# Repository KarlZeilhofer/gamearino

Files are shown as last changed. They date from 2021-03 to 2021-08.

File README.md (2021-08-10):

# Gamearino

Elektronisches Spielgerät mit 
* Gameboy Tastenlayout
* OLED-Display mit 128x64 Pixel
* Controller: ESP8266EX (Modul ESP-12F)

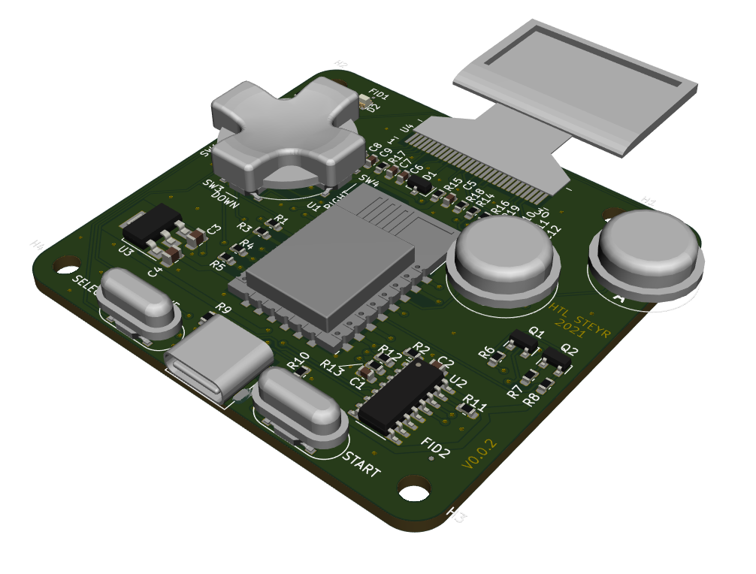
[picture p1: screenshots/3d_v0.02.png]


# OLED
wurde getestet mit dem Arduino Nano mit der Adafruit-Lib. Weil wir keinen Reset-Pin haben, 
muss das Display etwas anders initialisiert werden: 
''display.begin(SSD1306_SWITCHCAPVCC, 0x3c, false);''

Die I2C-Adresse jedenfalls ist 0x3c anstatt 0x3d (Default aus Example Code). 

# Arduino IDE
* ESP8266 installieren: 
  http://arduino.esp8266.com/stable/package_esp8266com_index.json
* Adafruit SSD1306 Lib: 
  Achtung: I2C-Adresse auf 0x3c:
  #define SCREEN_ADDRESS 0x3c

  I2C-Schnittstelle auf GPIO2 und GPIO14 festlegen:
  Wire.begin(14,2); // SDA, SCL
  
# Spiele
Für diese Plattform gibt es zwei Sorten von Spielen: 
1. HTL-Spiele: Spiele von Schülern entwickelt, befindens sich in diesem Repository im Ordner "arduino": https://github.com/KarlZeilhofer/gamearino/tree/main/arduino
2. Arduboy2: Spiele von Profis programmiert. Das originale Repository wurde um die Hardwareportierung erweitert und befindet sich hier: https://github.com/KarlZeilhofer/esp8266_arduboy2

## HTL-Spiele
Für die HTL-Spiele werden folgende Bibliotheken benötigt:
* Adafruit_BusIO
* Adafruit_GFX_Library
* Adafruit_SSD1306
* ESP_EEPROM

## Arduboy Spiele
Für die Arduboy-Spiele braucht es das zweite Repository: https://github.com/KarlZeilhofer/esp8266_arduboy2 und die zugehörigen Bibliotheken, siehe README.md dort. 

# Links
* Arduino ES8266 Core Dokumentation: https://arduino-esp8266.readthedocs.io/en/latest/
* Wikipedia: https://en.wikipedia.org/wiki/ESP8266
* OLED I2C vs. SPI on Youtube: https://www.youtube.com/watch?v=Wz6Fzo3rsLM
* https://www.heise.de/ct/artikel/Arduino-IDE-installieren-und-fit-machen-fuer-ESP8266-und-ESP32-4130814.html
* http://stefanfrings.de/esp8266/
* Adafruit Graphics Library Documentation: https://learn.adafruit.com/adafruit-gfx-graphics-library/overview

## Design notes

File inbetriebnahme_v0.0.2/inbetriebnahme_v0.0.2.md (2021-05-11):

* Bei der Bestückung wurden soll 10k mit ist 12k bestückt, weil keine 10k vorhanden waren. 
* Statt der BAV99 wurde ein NPN-Transistor verwendet für den OLED-Reset. 

* Kurzschluss beim USB-C - Pin in Paste noch suboptimal?
  Pastenauftrag war leicht verschmiert. 

* Die Autoreset-Transistoren sind falsch belegt. 
  Wurde durch drehen um 120° und mit Drahtbrücke gelöst. 
  --> MCU Ist nun programmierbar. 

* OLED Beschaltung optimiert, siehe Screenshot:
  * R17 überbrückt
  * Kathode der Diode auf 3.3V gehängt. 

* Fehler in OLED-Pin-Reihenfolge wurde durch Kupferlackdraht und Skalpell behoben

* SDA und SCL sind im Schaltplan falsch am OLED-Display angeschlossen: 
  IST: 19+20=SCL, 18=SDA
  SOLL: 18 = SCL, 19+20 = SDA

* SCL und SDA wurde in Software ausgetauscht:
  Richtig ist nun: Wire.begin(14, 2) // SDA, SCL

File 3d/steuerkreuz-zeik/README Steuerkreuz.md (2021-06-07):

Steuerkreuz nach dem Vorbild vom Nintendo Gameboy
=================================================

# 3D-Design in FreeCAD
Außenmaße: 21mm
Schenkelbreite: 7mm

Mitte-Mitte-Abstand der SMD-Taster: 14mm

Bauteilhöhe: 5.8mm (von Platinenoberfläche)
Rückhalter: auf Höhe 1.8 bis 2.8mm (1mm dick), 18mm Durchmesser

Kugel: 3mm Radius, liegt auf Platine auf
Kugelausnehmung für Daumen: 25mm Radius
zugehöriger Übergangsradius zur oberen H-Fläche: 5mm

Radius der Innenecken des Kreuzes: 2mm
Radius der Außenecken des Kreuzes: 0.8mm

# 3D-Druck mit Prusa Slicer
0.1mm Schichthöhe
z-Split auf Höhe 2.8mm

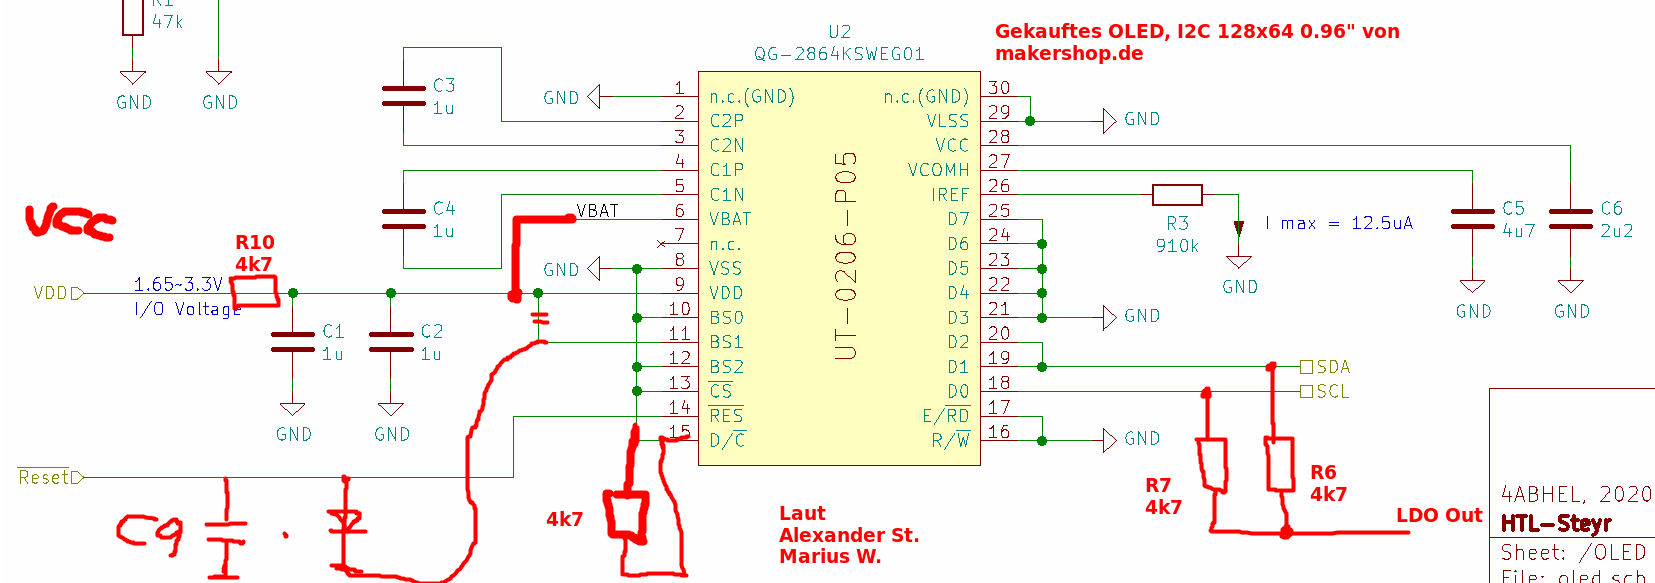
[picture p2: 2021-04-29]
brainstorming/oled-reverse-engineered.png

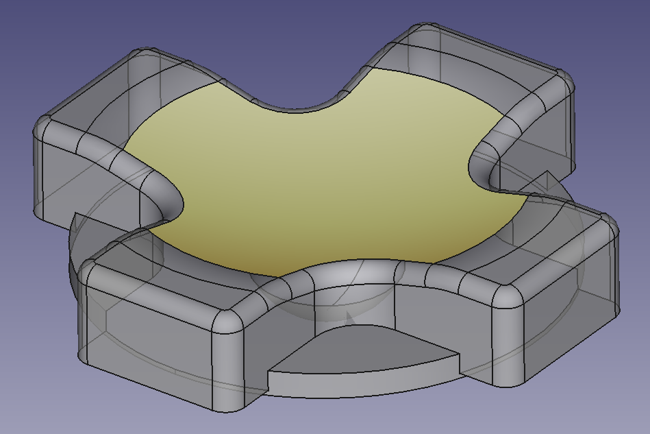
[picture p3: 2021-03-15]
3d/steuerkreuz-zeik/Screenshot from 2021-03-15 12-44-10.png

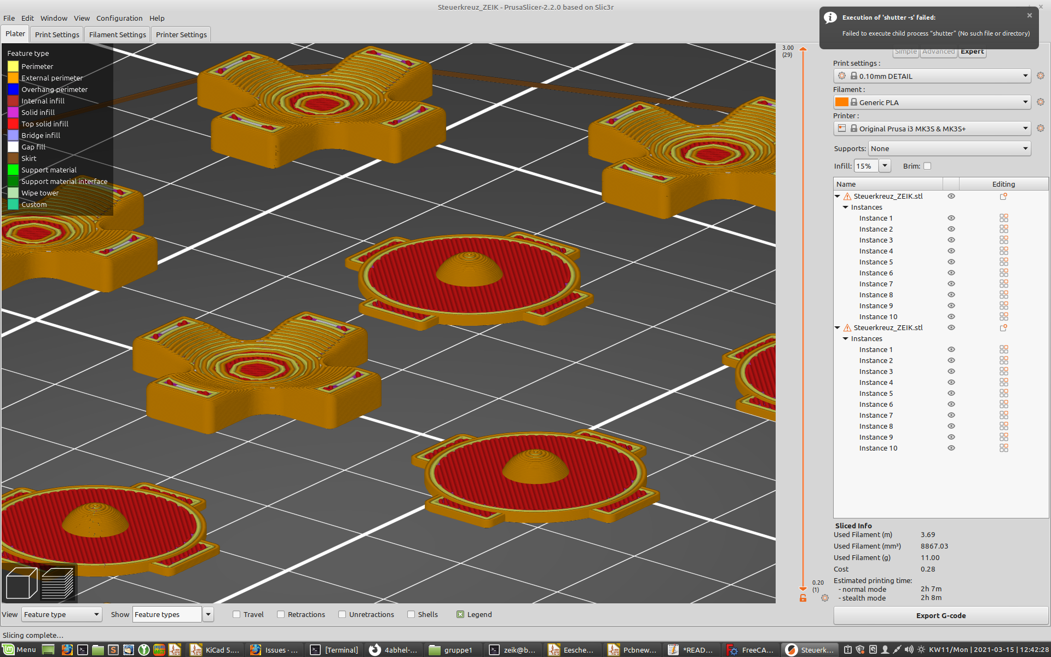
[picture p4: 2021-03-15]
3d/steuerkreuz-zeik/Screenshot from 2021-03-15 12-42-28.png

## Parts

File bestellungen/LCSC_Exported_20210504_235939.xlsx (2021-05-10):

LCSC Part Number | Manufacture Part Number | Manufacturer | Package | Customer # | Description | RoHS | Order Qty. | Min\Mult Order Qty. | Unit Price | Order Price | Product Link
C150387 | CR16-512FV | HDK(Hokuriku Elec Industry) | 0603 |  | 5.1kΩ ±1% 0.1W 0603 Chip Resistor - Surface Mount RoHS | yes | 60 | 20 | 0.0257 | 1.54 | lcsc.com/product-detail/Chip-Resistor-Surface-Mount_HDK-Hokuriku-Elec-Industry-CR16-512FV_C150387.html
C103210 | RTT03103JTP | RALEC | 0603 |  | 10kΩ ±5% 0.1W ±100ppm/℃ 0603 Chip Resistor - Surface Mount RoHS | yes | 600 | 100 | 0.0013 | 0.78 | lcsc.com/product-detail/Chip-Resistor-Surface-Mount_RALEC-RTT03103JTP_C103210.html
C1592 | CL10A105KO8NNNC | Samsung Electro-Mechanics | 0603 |  | 1uF ±10% 16V X5R 0603 Multilayer Ceramic Capacitors MLCC - SMD/SMT RoHS | yes | 350 | 50 | 0.0059 | 2.07 | lcsc.com/product-detail/Multilayer-Ceramic-Capacitors-MLCC-SMD-SMT_Samsung-Electro-Mechanics-CL10A105KO8NNNC_C1592.html
C318884 | TS-1187A-B-A-B | XKB Connectivity | SMD |  | SPST 50mA @ 12VDC Vertical Round Button 160gf SMD Tactile Switches RoHS | yes | 250 | 50 | 0.0155 | 3.88 | lcsc.com/product-detail/Tactile-Switches_XKB-Connectivity-TS-1187A-B-A-B_C318884.html
C103204 | RTT03101JTP | RALEC | 0603 |  | 100Ω ±5% 0.1W ±100ppm/℃ 0603 Chip Resistor - Surface Mount RoHS | yes | 300 | 100 | 0.0031 | 0.93 | lcsc.com/product-detail/Chip-Resistor-Surface-Mount_RALEC-RTT03101JTP_C103204.html
C8667 | PMBT3904,215 | Nexperia | SOT-23(SOT-23-3) |  | NPN 200mA 40V 250mW SOT-23(SOT-23-3) Transistors (NPN/PNP) RoHS | yes | 150 | 50 | 0.013 | 1.95 | lcsc.com/product-detail/Transistors-NPN-PNP_Nexperia-PMBT3904-215_C8667.html
C1713 | CL21A106KOQNNNE | Samsung Electro-Mechanics | 0805 |  | 10uF ±10% 16V X5R 0805 Multilayer Ceramic Capacitors MLCC - SMD/SMT RoHS | yes | 150 | 50 | 0.0147 | 2.21 | lcsc.com/product-detail/Multilayer-Ceramic-Capacitors-MLCC-SMD-SMT_Samsung-Electro-Mechanics-CL21A106KOQNNNE_C1713.html
C181111 | BAV99 | Guangdong Hottech | SOT-23 |  | 70V 200mA 1.25V @ 150mA 6ns SOT-23 Switching Diode RoHS | yes | 100 | 50 | 0.0116 | 1.16 | lcsc.com/product-detail/Switching-Diode_Guangdong-Hottech-BAV99_C181111.html
C125104 | LTST-C195KGJRKT | Lite-On | 0603_x2 |  | Red,Green 631nmRed,571nmGreen 0603_x2 Light Emitting Diodes (LED) RoHS | yes | 80 | 10 | 0.0402 | 3.22 | lcsc.com/product-detail/Light-Emitting-Diodes-LED_Lite-On-LTST-C195KGJRKT_C125104.html
C347222 | AMS1117-3.3 | UMW(Youtai Semiconductor Co., Ltd.) | SOT-223 |  | Fixed 10V 3.3V 1.3V @ 1A SOT-223 Dropout Regulators(LDO) RoHS | yes | 40 | 10 | 0.0559 | 2.24 | lcsc.com/product-detail/Dropout-Regulators-LDO_UMW-Youtai-Semiconductor-Co-Ltd-AMS1117-3-3_C347222.html
C84681 | CH340C | WCH(Jiangsu Qin Heng) | SOP-16_150mil |  | Transceiver USB 2.0 2Mbps SOP-16_150mil USB ICs RoHS | yes | 36 | 1 | 0.3787 | 13.63 | lcsc.com/product-detail/USB-ICs_WCH-Jiangsu-Qin-Heng-CH340C_C84681.html
C82891 | ESP-12F(ESP8266MOD) | Ai-Thinker | WIFI Module |  | WIFI Module WiFi Modules RoHS | yes | 36 | 1 | 1.4941 | 53.79 | lcsc.com/product-detail/WiFi-Modules_Ai-Thinker-ESP-12F-ESP8266MOD_C82891.html
C85007 | QG-2864KSWEG01 | Shenzhen Allvision Tech | 0.96" |  | 0.96" OLED Displays Modules RoHS | yes | 36 | 1 | 2.8953 | 104.23 | lcsc.com/product-detail/OLED-Displays-Modules_Shenzhen-Allvision-Tech-QG-2864KSWEG01_C85007.html
C167321 | 918-418K2023S40001 | Jing Extension of the Electronic Co. | SMD |  | USB - Type C Female 16 SMD USB Connectors RoHS | yes | 36 | 1 | 0.2443 | 8.79 | lcsc.com/product-detail/USB-Connectors_Jing-Extension-of-the-Electronic-Co-918-418K2023S40001_C167321.html

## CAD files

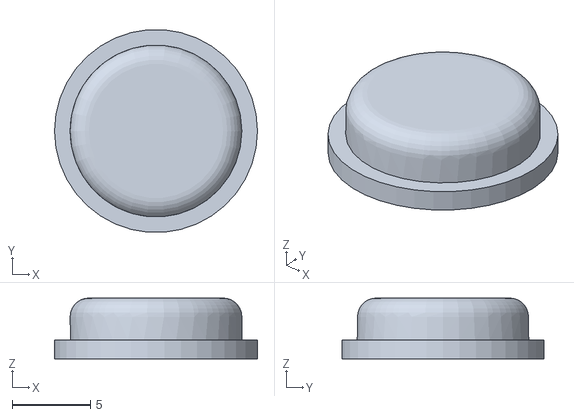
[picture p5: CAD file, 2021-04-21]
3d/ab-buttons/ab-button_v2.stl
13.0 x 13.0 x 3.90

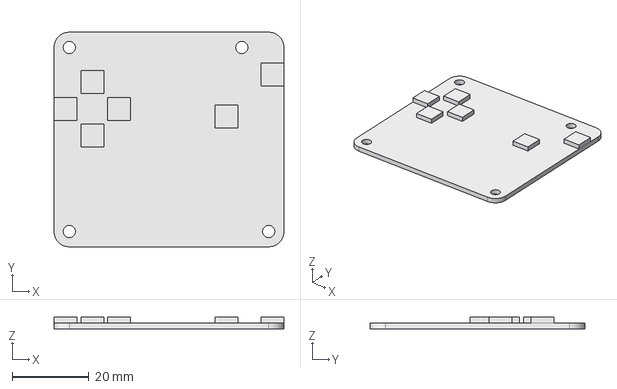
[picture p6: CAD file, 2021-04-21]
3d/dummy-pcb/dummy-pcb.FCStd
60.0 x 56.0 x 3.10 mm

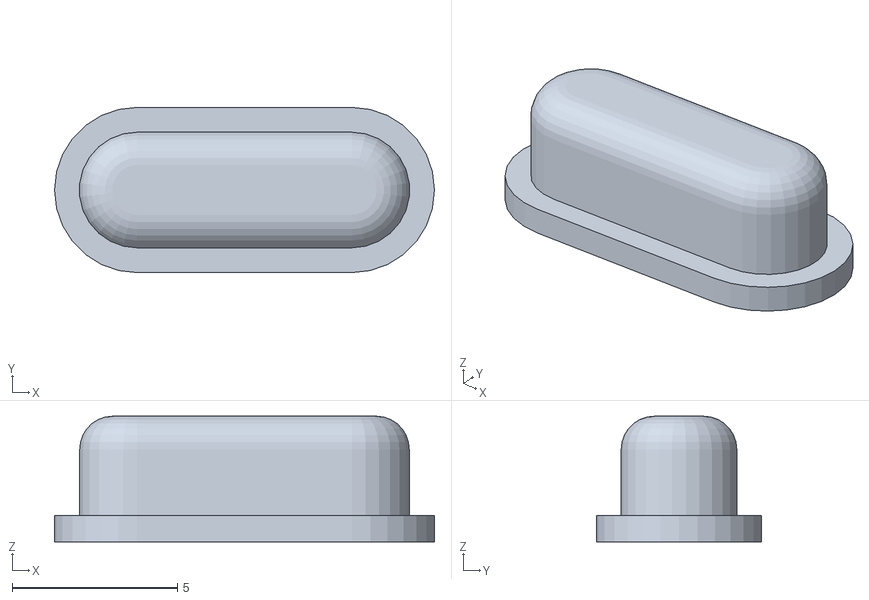
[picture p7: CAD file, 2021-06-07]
3d/gehäuse/gamearino-button_ss_v3.stl
11.5 x 5.00 x 3.80

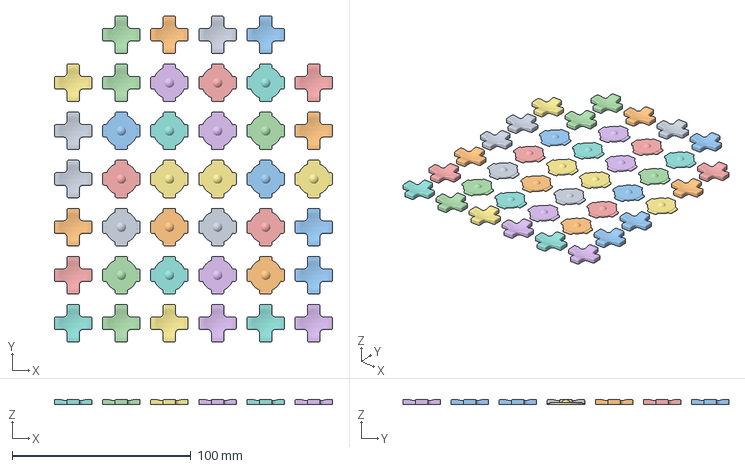
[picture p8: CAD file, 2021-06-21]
3d/prusa/gamearino-steuerkreuz_v2.3mf
155.6 x 182.4 x 3.00 mm
gamearino-steuerkreuz_v2.stl x 2

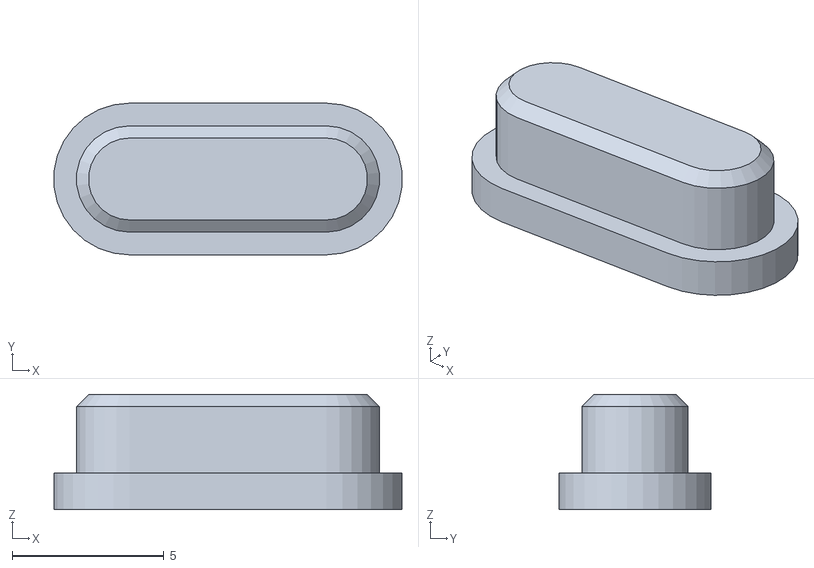
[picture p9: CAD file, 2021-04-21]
3d/start-select-buttons/start-select-button_v1.stl
11.5 x 5.00 x 3.80

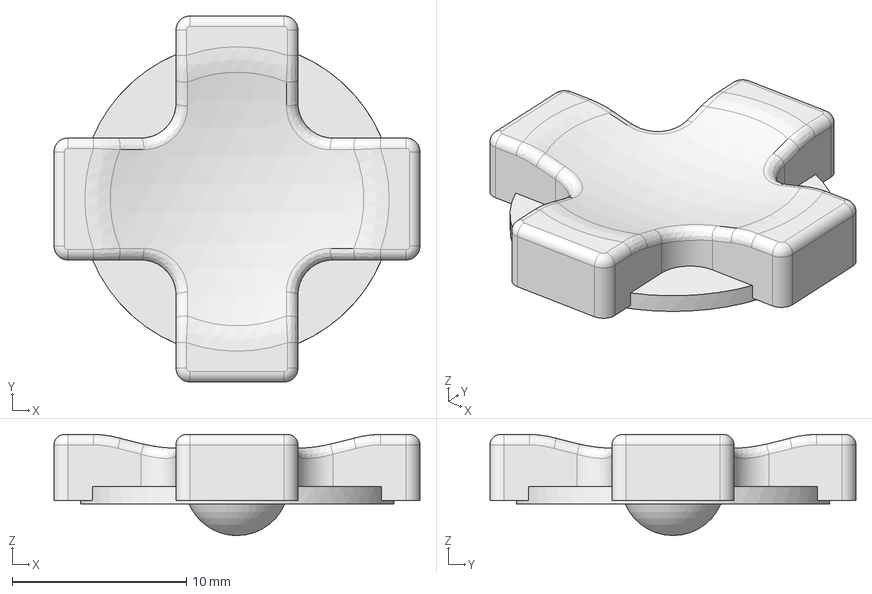
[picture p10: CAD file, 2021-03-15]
3d/steuerkreuz-zeik/steuerkreuz_gameboy_21x7x5.8mm.FCStd
21.0 x 21.0 x 5.80 mm

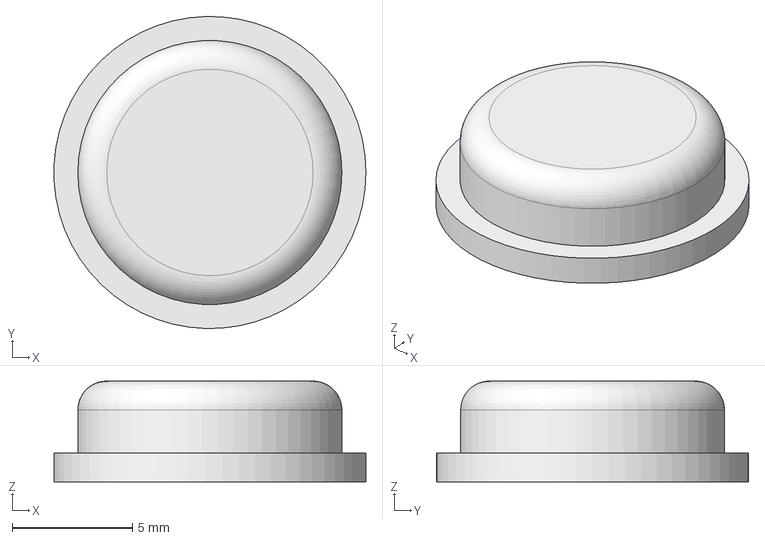
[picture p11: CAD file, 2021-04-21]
3d/ab-buttons/ab-buttons.FCStd
13.0 x 13.0 x 4.20 mm

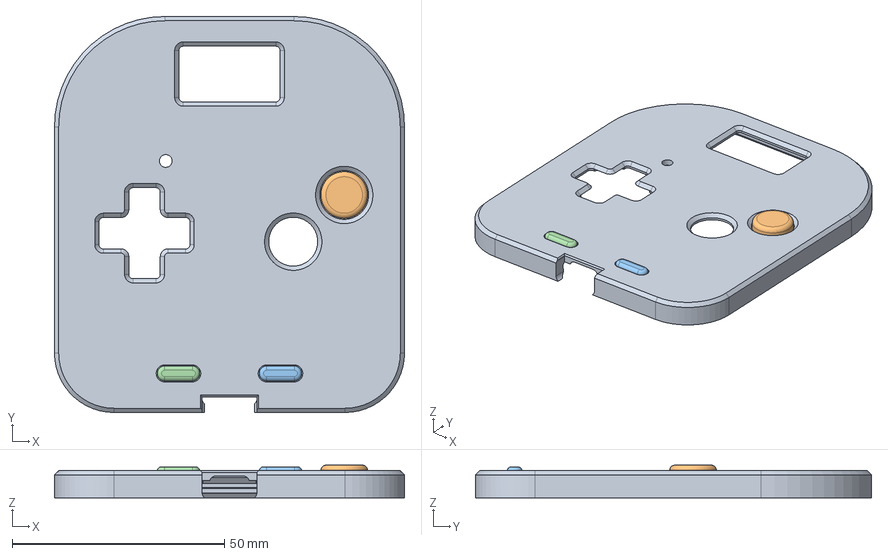
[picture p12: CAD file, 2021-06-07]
3d/gehäuse/gamearino-gehäuseboden.FCStd
82.4 x 93.2 x 7.70 mm
Deckel_v2
Button-A_v3
start-button_v3
select-button_v3

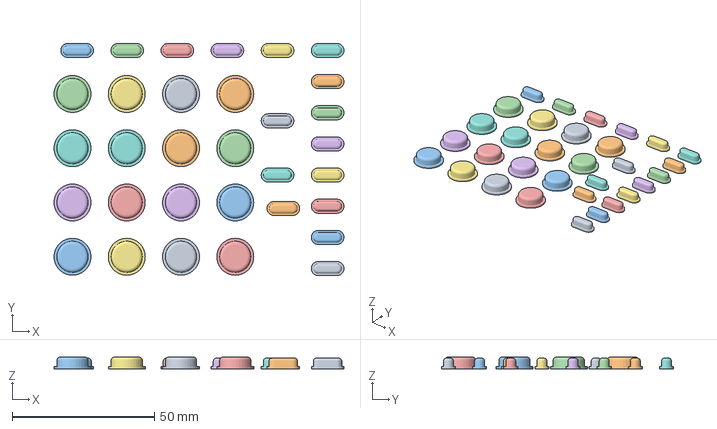
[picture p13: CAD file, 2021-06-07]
3d/prusa/gamearino-buttons_8sets_v3.3mf
101.9 x 81.6 x 4.20 mm
gamearino-button_ab_v3.stl
gamearino-button_ss_v3.stl

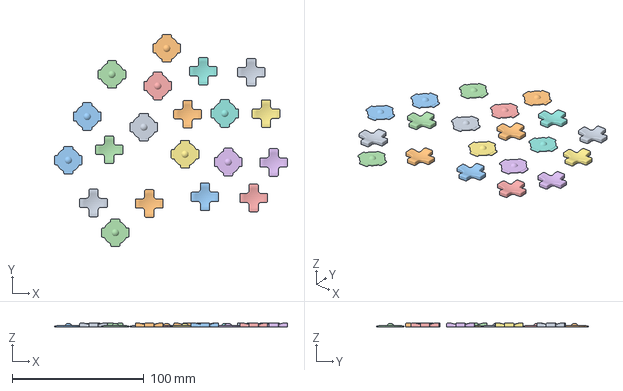
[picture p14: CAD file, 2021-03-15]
3d/steuerkreuz-zeik/Steuerkreuz_ZEIK.3mf
176.8 x 160.8 x 3.00 mm
Steuerkreuz_ZEIK.stl x 2

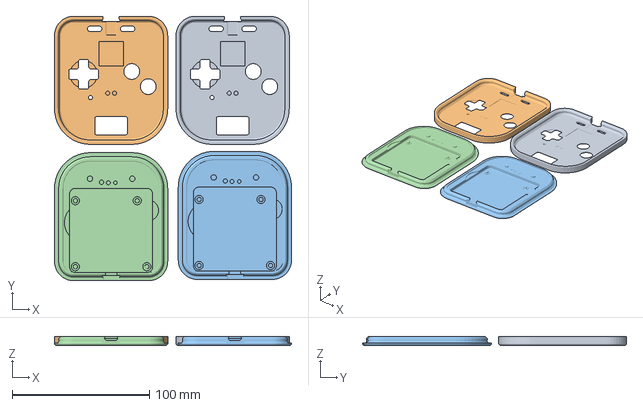
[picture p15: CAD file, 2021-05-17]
3d/prusa/gamearino_deckel-v2_boden-v3.3mf
172.4 x 192.4 x 6.40 mm
gamearino-deckel_v2.stl
gamearino-boden_v3.stl

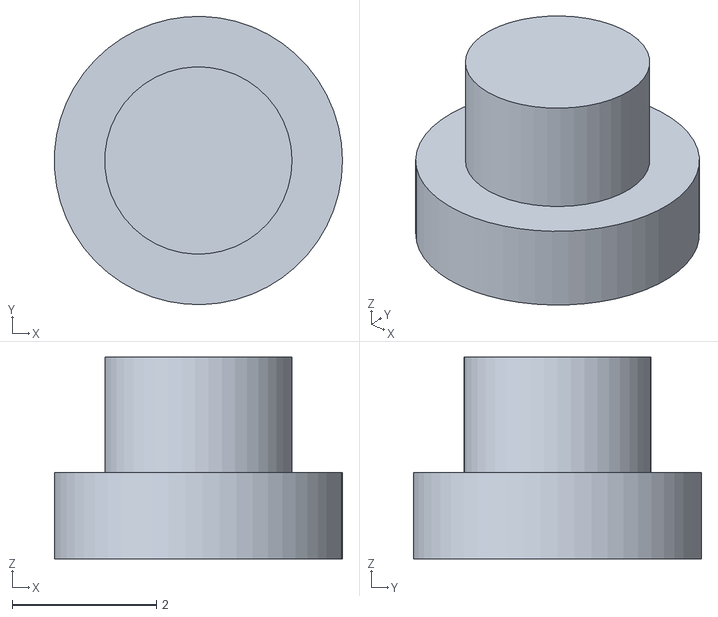
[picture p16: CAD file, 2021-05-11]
3d/gehäuse/gamearino-button_reset_v1.stl
4.00 x 4.00 x 2.80

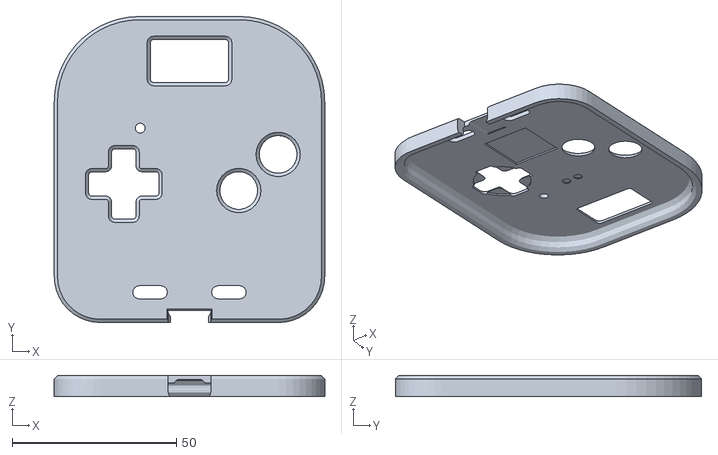
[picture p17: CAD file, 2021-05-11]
3d/gehäuse/gamearino-deckel_v2.stl
82.4 x 93.2 x 6.40

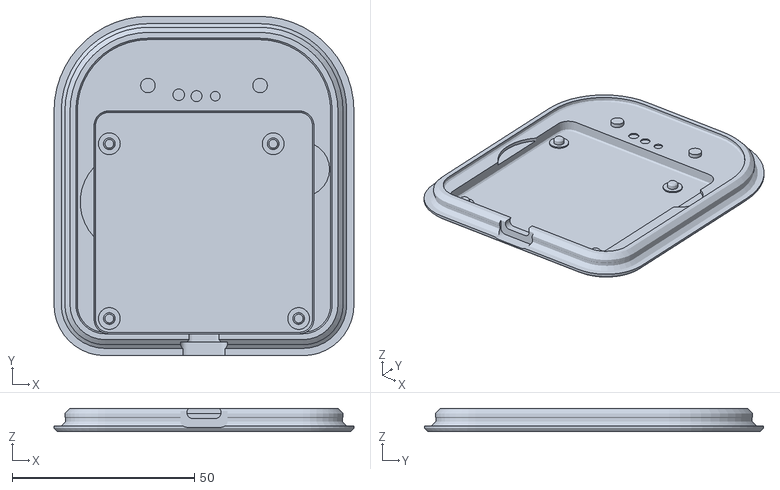
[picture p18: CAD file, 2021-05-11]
3d/gehäuse/gamearino-boden_v3.stl
82.4 x 93.2 x 6.40

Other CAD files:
3d/start-select-buttons/start-slect-button.FCStd
3d/gehäuse/gamearino-button_ab_v3.stl
3d/gehäuse/gamearino-steuerkreuz_v2.stl
3d/gehäuse/gamearino-deckel_v0.1.stl
3d/dummy-pcb/dummy-pcb.stl
3d/gehäuse/gamearino-boden_v1.stl
3d/gehäuse/gamearino-boden_v2.stl
3d/gehäuse/gamearino-button_ab_v2.stl
3d/gehäuse/gamearino-button_ss_v2.stl
3d/gehäuse/gamearino-deckel_v1.stl
3d/steuerkreuz-zeik/Steuerkreuz_ZEIK.stl

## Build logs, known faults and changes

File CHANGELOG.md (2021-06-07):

Changelog Gamearino
===================

# Elektronik
## V20.0.3 Bugfixes für Erste Serienfertigung
* Reset-Taster hinzugefügt
* DNP Footprint für Kondensator am Reset-Pin
* OLED-Beschaltung korrigiert
* OLED Footprint korrigiert
* NPN Pinnummerierung korrigiert
* 0.7mm-Löcher bei der OLED-Flex-PCB
* Pulldown auf Pin 15 durch fix GND ersetzt
* SDA/SCL richtig gestell
* Gerber Export
* HTML-BOM Export
* Durchgehend V20.0.3

## V0.0.2 Prototyp Multi-CB
* Bauteilsortenreduktion beim LCD: 10uF statt 4.7uF, und 2x1uF statt 2.2uF
* Terminierung der unbenutzten Eingänge am CH340
* 5k1 auf CC1 und CC2 bei USB-C-Stecker
* Verwendung des neuen USB-C Footprints mit Pin in Paste
* Pastenreduktion 30um
* Lötstoppfreistellung: 51um
* 150um Leiterbahnabstand
* 150um Mindestleiterbahnbreite
* Passmarken für SMD-Schablone
* 3D-Modelle für Taster und Steuerkreuz aktualisiert
* Taster beschriftet
* Beschriftungen auf PCB-Rückseite
* Power-LED hinzugefügt (Doppel LED, rot aktiv)
* Bestellung 3 Stk. bei Multi-CB inkl. SMD-Schablone mit 120um

## V0.0.1 - CNC-Prototyp
* Grundbeschaltung des ESP8266 ESP-12F:
  * 10k auf GPIO15 gegen GND
  * 10k auf Enable gegen 3V3
* Programmierschaltung mit Transistoren auf Steckbrett getestet
  Arduino-IDE, Standardeinstellung für NodeMCU 1.0
* OLED-Beschaltung auf Steckbrett getestet
* 3D-Design der Taster und des Steuerkreuzes
* Die 8 Taster werden über eine 3x3-Tastermatrix ausgewertet
* Autoreset: unterer Transistor gespiegelt. Beide sind NPN. 
* Pinbelegungsliste als .ods-Datei
* Bemaßungen der Taster
* TODOs aktualisiert: ESP mit OLED erfolgreich getestet
* OLED Demoprogramm
* Tastenanordnung Start/Select und A/B wie beim Original Gameboy (TM)
* USB-Footprint optimiert, inkl. Pin in Paste
* Layout für CNC-Fertigung (ca. 60 Vias!)

# 3D-Druck
* Steuerkreuz: Unterkante von 1.8mm auf Niveau +1.6mm abgesenkt, Haltering bleibt oben +2.8mm
* Gehäuseboden gestaltet
* Dummy-PCB
* Gehäusedeckel probegedruckt
* Deckel-Boden-Paarung: mit 0.2mm-Nut, und identischen Konturen passt es perfekt zusammen
* 3D-Druckteile auf 0.2mm Schichthöhe optimiert (außer Steuerkreuz)
* Deckel V2: 
  * Displayausschnitt nach oben geschoben und rundherum um 1mm vergrößert
  * Senkung für Steuerkreuz von 0,4 auf 0,6mm vergrößert (Steuerkreuz spießt sich bisher)
  * Versionskerben
  * ESP-Senkung mit 0.6 mm (der ist minimal dicker als 2.8 mm)
* Boden V3: 
  * Montage-Sockeln: Stutzen von Durchmesser 3.0 auf 3.2 mm vergrößert
  * Versionskerben
  * Senkungen für Steuerkreuz und A-Taster im Gehäuserand
* Buttons (A/B und Start/Select) V3:
  * Rückhaltesteg von 1.2mm auf 0.8mm reduziert, Knöpfe klemmten im Gehäuse, sodass der Taster immer gedrückt war
  * Gesamtdickt gleich belassen
## TODOs
* Gehäuse dokumentieren

# Spiele
## Snake
* Grundsätzliche Funktion vorhanden
* Button-Klasse in Hardware-Test implementiert
* Highscore
* Asynchrones Warten und Tasten einlesen

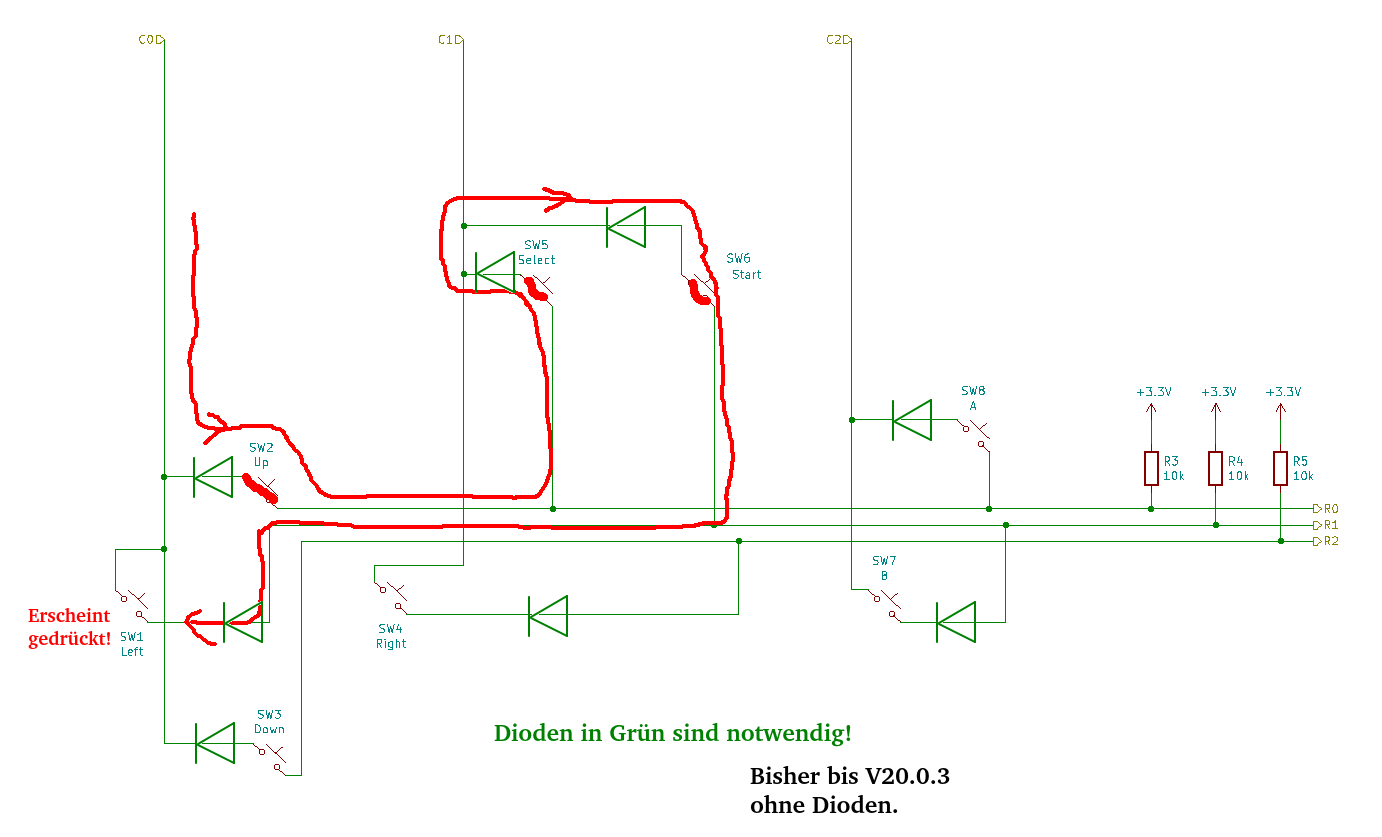
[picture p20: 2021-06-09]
bugreports/issue20.png

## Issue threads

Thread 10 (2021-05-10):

Reset über RTS nach Flashen funktioniert nicht richtig

KarlZeilhofer, 2021-05-10:
evt. sollte noch 1uF zum Resetpin geschaltet werden, siehe ESP-Wroom-Audio. In v0.0.2 ist gar kein Kondensator am Reset

KarlZeilhofer, 2021-05-11:
Das Problem konnte nun nicht mehr festgestellt werden. Ein Footprint wird jedoch vorgesehen in V20.0.3

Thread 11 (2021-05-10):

Reset-Taster wäre nicht schlecht

KarlZeilhofer, 2021-05-10:
Die ersten UART-Ausgaben sind ohne dem Reset-Taster nicht zu sehen.

Bedienung über zusätzlichen Drückknopf oder über Loch im Deckel für Büroklammer.

KarlZeilhofer, 2021-05-11:
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

Closed 2021-05-11.

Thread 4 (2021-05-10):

Deckel/Steuerkreuz: Steuerkreuz ist schwergängig

KarlZeilhofer, 2021-05-10:
Es lässt sich nur die linke Taste leicht drücken. Offenbar fehlt der Freiraum nach oben an der gegenüberliegenden Seite.

KarlZeilhofer, 2021-05-11:
Senkung wurde von 0,4 mm auf 0,6 mm im Deckel vergrößert

Closed 2021-05-11.

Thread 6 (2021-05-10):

PCB: 0.7mm-Löcher bei der Flex-Leiterplatte zu klein

KarlZeilhofer, 2021-05-10:
v0.0.2: sollten 0.7mm haben, sind aber nur 0,4mm

KarlZeilhofer, 2021-05-11:
wurde in v20.0.3 korrigiert

Closed 2021-05-11.

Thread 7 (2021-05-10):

OLED-Beschaltung

KarlZeilhofer, 2021-05-10:
Verbesserungsvorschläge, ausgehend vom Stand v0.0.2:
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

Viele Hinweise auf eevBlog Forum: https://www.eevblog.com/forum/beginners/cant-get-ssd1306-oled-working-on-custom-pcb/

KarlZeilhofer, 2021-05-11:
# SDA und SCL sind auch vertauscht!
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

KarlZeilhofer, 2021-05-11:
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

Gefixt in V20.0.3

Closed 2021-05-11.

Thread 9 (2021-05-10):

Pin-Belegung NPN PMBT3904,215 falsch!

KarlZeilhofer, 2021-05-10:
In v0.0.2 ist diese Belegung zu finden:
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

Laut Datenblatt ist aber folgende Belegung:
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

D.h. statt Device:Q_NPN_BCE muss Device:Q_NPN_BEC verwendet werden!

KarlZeilhofer, 2021-05-11:
![Uploading 2021-05-11_007.png…]()

KarlZeilhofer, 2021-05-11:
# V20.0.3:

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

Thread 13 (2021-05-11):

Reset-Taster Designen

KarlZeilhofer, 2021-05-11:
Deckel Oberseite ist auf 4,4mm
Deckel Unterseite ist auf 2,8mm
Taster ungedrückt auf 1,5mm

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

KarlZeilhofer, 2021-06-09:
Passt perfekt

Closed 2021-06-09.

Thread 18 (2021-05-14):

Snake: Wird sporadisch beendet

KarlZeilhofer, 2021-05-14:
Hier liegt ein Bug vor, dass während des normalen Spiels, das Spiel beendet wird, als ob man gegen eine Wand oder die Schlange gefahren wäre. Ich hab schon bis zu 32 Punkte erreicht, manchmal passiert das aber schon mit 6 Punkten.

KarlZeilhofer, 2021-05-14:
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

Bug wurde gefunden und in commit 28f7e240cf821dac9837e5fc96d309608dc1e1ef behoben

KarlZeilhofer, 2021-05-14:
# Fehlerhaftes Beenden:

## Hier ist offensichtlich, dass die Schlange gar nicht richtig interpretiert wird.
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

## Auch hier wurde das Spiel aus heiterem Himmel beendet:
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

## Korrekte Darstellung und Eigenkollision nach dem Bugfix:
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

Closed 2021-05-14.

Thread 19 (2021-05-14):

Arduboy-Spiele portieren

KarlZeilhofer, 2021-05-14:
Es gibt ein super Projekt dazu:
https://github.com/cheungbx/esp8266_arduboy2

Ich hab es bereits geklont, und die Tasten-Eingabe auf Gamearino umgeschrieben:
https://github.com/KarlZeilhofer/esp8266_arduboy2

Closed 2021-06-09.

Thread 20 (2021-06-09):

Button Matrix Diodes missing

MerlinBlatterer, 2021-06-09:
Diodes in the button matrix are missing.
They are needed in order to prevent ghosting.
One diode for each button

MerlinBlatterer, 2021-06-09:
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

KarlZeilhofer, 2021-06-09:
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

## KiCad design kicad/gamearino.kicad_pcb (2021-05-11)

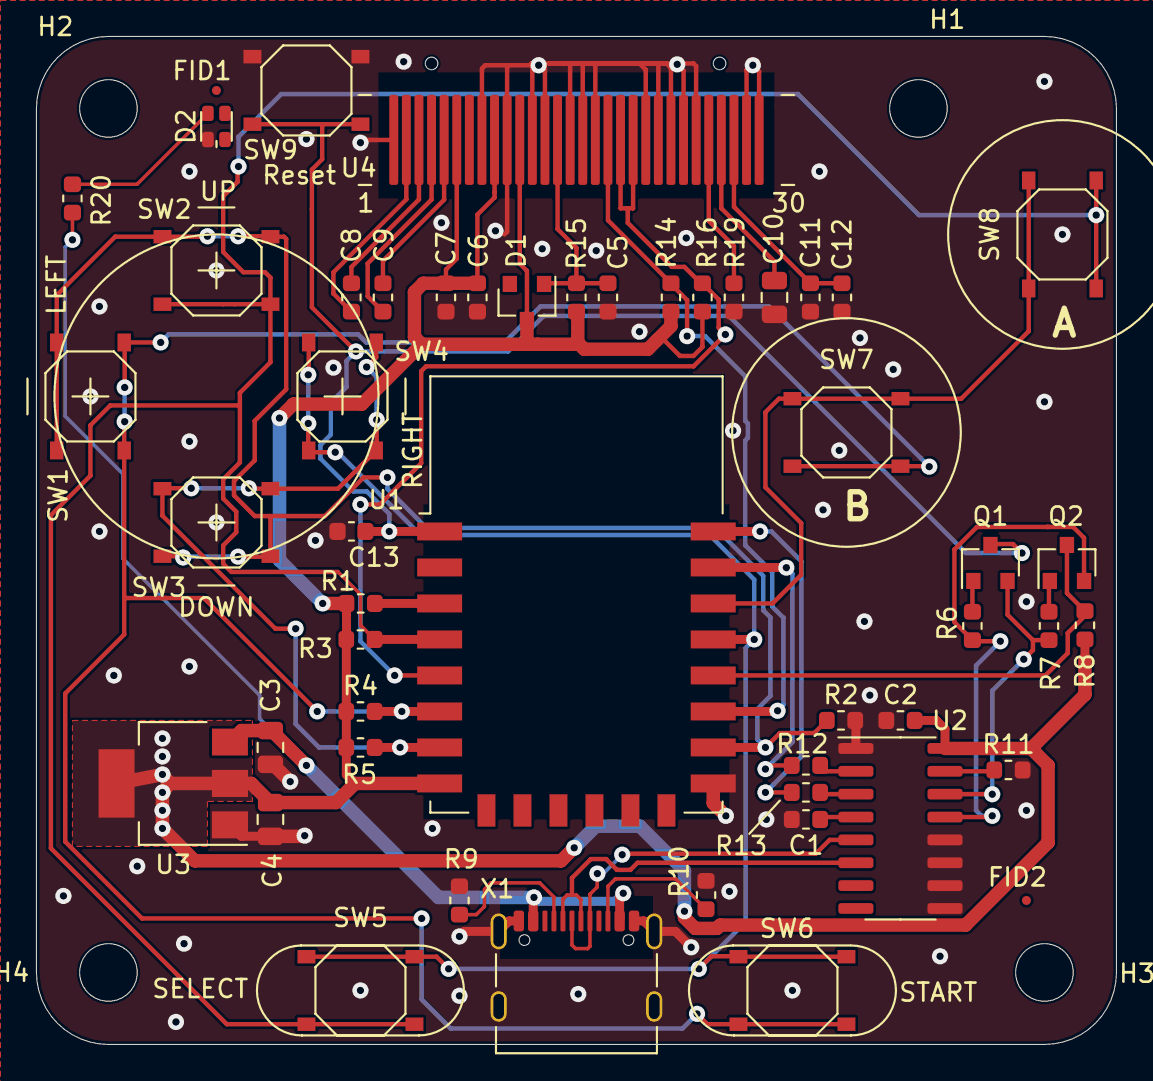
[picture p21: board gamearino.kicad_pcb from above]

Board: 2 copper layers, 60.0 x 56.0 mm, 60 parts (0 on the bottom side), 37 nets.

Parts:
C1, C2: 100n; C_0603_1608Metric
C3, C4, C10: 10u/16V/X5R; C_0805_2012Metric
C5, C6, C7, C8, C9, C11, C12: 1u; C_0603_1608Metric
C13: DNP; C_0603_1608Metric
D1: BAV99; SOT-23
D2: LED_Dual_green-red; LED_LiteOn_LTST-C195KGJRKT
FID1, FID2: Fiducial; paste-fiducial
H1, H2, H3, H4: MountingHole; MountingHole_3.2mm_M3
Item1: 3D Druck: Knopf A; ABKnopf_v2
Item2: 3D Druck: Knopf B; ABKnopf_v2
Item3: 3D Druck: Knopf Start; StartSelect_v2
Item4: 3D Druck: Knopf Select; StartSelect_v2
Item5: 3D Druck: Steuerkreuz; Steuerkreuz_zeik_v2
Q1, Q2: PMBT3904,215; SOT-23
R1, R2, R3, R4, R5, R6, R7, R15: 10k; R_0603_1608Metric
R8, R14, R16, R20: 4k7; R_0603_1608Metric
R9, R10: 5k1; R_0603_1608Metric
R11, R12, R13: 100R; R_0603_1608Metric
R19: 910k; R_0603_1608Metric
SW1: Left; SW_Push_5.1mm_H1.5mm
SW2: Up; SW_Push_5.1mm_H1.5mm
SW3: Down; SW_Push_5.1mm_H1.5mm
SW4: Right; SW_Push_5.1mm_H1.5mm
SW5: Select; SW_Push_5.1mm_H1.5mm
SW6: Start; SW_Push_5.1mm_H1.5mm
SW7: B; SW_Push_5.1mm_H1.5mm
SW8: A; SW_Push_5.1mm_H1.5mm
SW9: Reset; SW_Push_5.1mm_H1.5mm
U1: ESP-12F
U2: CH340C; SOIC-16_3.9x9.9mm_P1.27mm
U3: AMS1117-3.3; SOT-223-3_TabPin2
U4: QG-2864KSWEG01; OLED_128x64_FlatRibbon_30
X1: USB-C/16p; USB_C_Receptacle_LCSC_C167321

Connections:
+3V3: C2.2, C4.1, C6.1, C7.1, D1.3, R1.1, R3.1, R4.1, R5.1, R8.1, R14.2, R15.1, R16.2, U1.8, U2.16, U3.2, U4.6, U4.9, U4.11
/Auto-Reset/DTR: Q2.2, R6.2, U2.13
/Auto-Reset/GPIO0: Q2.3, R8.2, U1.18
/Auto-Reset/RTS: Q1.2, R7.2, U2.14
/Buttons/C0: R2.1, SW1.1, SW2.1, SW3.1, U1.16
/Buttons/C1: SW4.1, SW5.1, SW6.1, U1.19
/Buttons/C2: SW7.1, SW8.1, U1.20
/Buttons/R0: R3.2, SW2.2, SW5.2, SW8.2, U1.4
/Buttons/R1: R4.2, SW1.2, SW6.2, SW7.2, U1.6
/Buttons/R2: R5.2, SW3.2, SW4.2, U1.7
/EN: R1.2, U1.3
/OLED 128x64/SCL: R14.1, U1.17, U4.18
/OLED 128x64/SDA: R16.1, U1.5, U4.19, U4.20
/USB/D+: U2.5, X1.A6, X1.B6
/USB/D-: U2.6, X1.A7, X1.B7
/USB/RxD: R13.1, U1.22
/USB/TxD: R12.2, U1.21
/~RESET: C13.1, Q1.3, SW9.2, U1.1
GND: C1.2, C2.1, C3.2, C4.2, C5.2, C6.2, C7.2, C10.2, C11.2, C12.2, C13.2, D2.4, R2.2, R9.1, R10.2, R11.2, R19.1, SW9.1, U1.15, U2.1, U2.9, U2.10, U2.11, U2.12, U3.1, U4.1, U4.8, U4.10, U4.12, U4.13, U4.15, U4.16, U4.17, U4.21, U4.22, U4.23, U4.24, U4.25, U4.29, U4.30, X1.A1, X1.A12, X1.B1, X1.B12, X1.S1
unnamed: C1.1, U2.4
unnamed: C3.1, R20.1, U3.3, X1.A4, X1.A9, X1.B4, X1.B9
unnamed: C5.1, D1.1, R15.2, U4.14
unnamed: C8.1, U4.2
unnamed: C8.2, U4.3
unnamed: C9.1, U4.4
unnamed: C9.2, U4.5
unnamed: C10.1, U4.27
unnamed: C11.1, C12.1, U4.28
unnamed: D2.2, R20.2
unnamed: Q1.1, R6.1
unnamed: Q2.1, R7.1
unnamed: R9.2, X1.A5
unnamed: R10.1, X1.B5
unnamed: R11.1, U2.15
unnamed: R12.1, U2.2
unnamed: R13.2, U2.3
unnamed: R19.2, U4.26

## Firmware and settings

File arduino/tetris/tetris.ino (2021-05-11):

//TETRIS - TODO-List:
//-Tetrominos müssen sich drehen können
//-Links-Rechts steuerung funktioniert noch nicht optimal, außerdem gibt es noch keine Grenze nach Links/Rechts
//-schnelleres Fallen mit DOWN Button
//-Reihe wird gecleared wenn alle Blöcke voll sind
//-Man verliert wenn man ganz oben ankommt
//-Der nächste Tetromino soll rechts angezeigt weden, so wie ein passender Score
//-Level System, nach gewisser Zeit fallen die Bläcke schneller






typedef struct point {
  uint8_t x;
  uint8_t y;
} point;
#define SCREEN_WIDTH 128 // OLED display width, in pixels
#define SCREEN_HEIGHT 64 // OLED display height, in pixels


#define SEGMENT_TIME 500//Zeit bis 1 Segment vorwärts
#define SEGMENT_SIZE 3
#define START_LEN 3
#define FIELD_SIZE_X 12
#define FIELD_SIZE_Y 21
#define ARR_LEN 100

// Button Matrix 
// UP      C0-R0
// DOWN    C0-R2
// LEFT    C0-R1
// RIGHT   C1-R2
// SELECT  C1-R0
// START   C1-R1
// B       C2-R1
// A       C2-R0


// MCU outputs:
#define MatrixC0 15
#define MatrixC1 4
#define MatrixC2 5
// MCU inputs (hardware pullups 10k):
#define MatrixR0 16
#define MatrixR1 12
#define MatrixR2 13

#define PinSTART 2
#define PinUP 3
#define PinDOWN 4
#define PinLEFT 5
#define PinRIGHT 6
#define TimePrell 30

#include <stdlib.h>
#include <time.h>
#include <SPI.h>
#include <Wire.h>
#include <Adafruit_GFX.h>
#include <Adafruit_SSD1306.h>
#include <EEPROM.h>


// Declaration for an SSD1306 display connected to I2C (SDA, SCL pins)
#define OLED_RESET     -1 // Reset pin # (or -1 if sharing Arduino reset pin)
Adafruit_SSD1306 display(SCREEN_WIDTH, SCREEN_HEIGHT, &Wire, OLED_RESET);


point [4] = {0};
point groundBlock[ARR_LEN] = {0};

uint16_t field [21] = {0};

int num;
uint16_t len = START_LEN;
uint8_t score = 0;
uint8_t highscore = 0;
bool gameRunning = false;
bool inLeaderboard = false;
uint8_t selectedOption = 0;
uint16_t oldtime;
uint16_t starttime;
uint16_t lasttoggle = 0;
int mult;
int turnstate;
int count;
int zw;
point eatPos;
bool firstBlock = true;

int chosenBlock;
int nextBlock

bool pinSTARTLow = true;
bool pinUPLow = true;
bool pinDOWNLow = true;
bool pinLEFTLow = true;
bool pinRIGHTLow = true;
bool pinSELECTLow = true;
bool pinA_Button = true;
bool pinB_Button = true;


unsigned long lastSTART = 0;
unsigned long lastUP = 0;
unsigned long lastDOWN = 0;
unsigned long lastLEFT = 0;
unsigned long lastRIGHT = 0;
unsigned long lastSELECT = 0;
unsigned long lastA_Button = 0;
unsigned long lastB_Button = 0;





enum Buttons {UP, DOWN, LEFT, RIGHT, START, EMPTY} button, oldButton;

uint8_t buttons; // Um mehrere Inputs gleichzeitig verarbeiten zu können
#define UP 1
#define DOWN 2
#define LEFT 4
#define Right 8
#define A_Button 16
#define B_Button 32
#define START 64
#define Select 128

#define LOGO_HEIGHT   16
#define LOGO_WIDTH    16


void setup() {

  Serial.begin(9600);
  Wire.begin(14,2); // SDA, SCL


  // SSD1306_SWITCHCAPVCC = generate display voltage from 3.3V internally
  if (!display.begin(SSD1306_SWITCHCAPVCC, 0x3C, false, false)) { // Address 0x3D for 128x64
    Serial.println(F("SSD1306 allocation failed"));
    for (;;); // Don't proceed, loop forever
  }
  Serial.print(F("Size of SSD1306: "));
  Serial.println(sizeof(display));
  display.clearDisplay();



  pinMode(PinSTART, INPUT_PULLUP);
  pinMode(PinUP, INPUT_PULLUP);
  pinMode(PinDOWN, INPUT_PULLUP);
  pinMode(PinLEFT, INPUT_PULLUP);
  pinMode(PinRIGHT, INPUT_PULLUP);


  if (digitalRead(PinSTART) == LOW && digitalRead(PinUP) == LOW) {

    for (uint8_t i = 0; i < 15; i++) {
      EEPROM.write(i, 0);
    }

  }

  // Clear the buffer
  printWelcomeScreen();

}


void startGame() {
  highscore = EEPROM.read(0);

  display.clearDisplay();
  button = RIGHT;
  oldButton = RIGHT;
  drawBorder();
  formBlock();
  printScore();
  printTime();
  gameRunning = true;
  starttime = millis() / 1000;

}
void printWelcomeScreen() {
  display.clearDisplay();
  display.setTextSize(1);
  display.setTextColor(WHITE);
  display.setCursor(35, 5);
  display.println("Welcome to:");
  display.setTextSize(2);
  display.setCursor(37, 20);
  display.println("TETRIS");
  display.setTextSize(1);
  display.setCursor(52, 43);
  display.println("START");
  display.setTextSize(1);
  display.setCursor(34, 55);
  display.println("LEADERBOARD");
  display.display();
}

void toggleText() {

  //
  uint16_t now = millis();

  if (now - lasttoggle > 1000) {

    lasttoggle = now;
    display.setTextColor(WHITE);
  } else if (now - lasttoggle > 500) {
    display.setTextColor(BLACK);
  } else {
    return;
  }

  if (selectedOption == 0) {
    display.setTextSize(1);
    display.setCursor(52, 43);
    display.println("START");
  } else {
    display.setTextSize(1);
    display.setCursor(34, 55);
    display.println("LEADERBOARD");
  }

  display.display();
}

void printLeaderBoard() {
  display.clearDisplay();
  display.setTextColor(WHITE);
  display.setTextSize(1);
  display.setCursor(0, 0);
  display.println("NUM: SCORE:   TIME:");
  for (uint16_t i = 0; i <= 4; i++) {
    display.drawRect(0, (i * 10) + 10, 20, 11, SSD1306_WHITE);
    display.drawRect(19, (i * 10) + 10, 50, 11, SSD1306_WHITE);
    display.drawRect(68, (i * 10) + 10, 60, 11, SSD1306_WHITE);
    display.setTextColor(WHITE);
    display.setTextSize(1);
    display.setCursor(8, (i * 10) + 12);
    display.println(i + 1);
    if (EEPROM.read(i * 3) != 0) {
      display.setCursor(35, (i * 10) + 12);
      display.println(EEPROM.read(i * 3));

      char pC16[2];
      pC16[0] = EEPROM.read(i * 3 + 1);
      pC16[1] = EEPROM.read(i * 3 + 2);
      uint16_t ui16;
      memcpy( &ui16, pC16, 2 );

      display.setCursor(85, (i * 10) + 12);
      display.println(ui16);
    }

  }

  display.display();
}

uint8_t getButtonPress() {
  uint8_t rv = 0;
// Button Matrix 
// UP      C0-R0
// DOWN    C0-R2
// LEFT    C0-R1
// RIGHT   C1-R2
// SELECT  C1-R0
// START   C1-R1
// B       C2-R1
// A       C2-R0
  // Test for UP, LEFT or DOWN
  digitalWrite(MatrixC0, LOW);
  digitalWrite(MatrixC1, HIGH);
  digitalWrite(MatrixC2, HIGH);

  if (millis() - lastUP > TimePrell) {
    int valUP = digitalRead(MatrixR0);
    if (checkButton(valUP, &pinUPLow, &lastUP) == true) {
      Serial.println("UP");
      rv |= UP;
    }
  }
  if (millis() - lastLEFT > TimePrell) {
    int valLEFT = digitalRead(MatrixR1);
    if (checkButton(valLEFT, &pinLEFTLow, &lastLEFT) == true) {
      Serial.println("LEFT");
      rv|= LEFT;
    }
  }
  if (millis() - lastDOWN > TimePrell) {
    int valDOWN = digitalRead(MatrixR2);
    if (checkButton(valDOWN, &pinDOWNLow, &lastDOWN) == true) {
      Serial.println("DOWN");
      rv |= DOWN;
    }
  }

  // Test for SELECT, START or RIGHT
  digitalWrite(MatrixC0, HIGH);
  digitalWrite(MatrixC1, LOW);
  digitalWrite(MatrixC2, HIGH);

  if (millis() - lastSELECT > TimePrell) {
    int valSELECT = digitalRead(MatrixR0);
    if (checkButton(valSELECT, &pinSELECTLow, &lastSELECT) == true) {
      Serial.println("SELECT");
      rv |= SELECT;
    }
  }

  if (millis() - lastSTART > TimePrell) {
    int valSTART = digitalRead(MatrixR1);
    if (checkButton(valSTART, &pinSTARTLow, &lastSTART) == true) {
      Serial.println("START");
      rv |= START;
    }
  }

  if (millis() - lastRIGHT > TimePrell) {
    int valRIGHT = digitalRead(MatrixR2);
    if (checkButton(valRIGHT, &pinRIGHTLow, &lastRIGHT) == true) {
      Serial.println("RIGHT");
      rv |= RIGHT;
    }
  }

  // Test for A, B or Reserved
  digitalWrite(MatrixC0, HIGH);
  digitalWrite(MatrixC1, HIGH);
  digitalWrite(MatrixC2, LOW);

// TODO: Implement A Button
if (millis() - lastA_Button > TimePrell) {
    int valA_Button = digitalRead(MatrixR0);
    if (checkButton(A_Button, &pinA_ButtonLow, &lastA_Button) == true) {
      Serial.println("A");
      rv |= A;
    }
  } 
  // TODO: Implement B Button
  if (millis() - lastB_Button > TimePrell) {
    int valB_Button = digitalRead(MatrixR1);
    if (checkButton(valB_Button , &pinB_ButtonLow, &lastB_Button ) == true) {
      Serial.println("B");
      rv |= B;
    }
  }
  // TODO: Implement Reserved Button


  digitalWrite(MatrixC0, HIGH);
  digitalWrite(MatrixC1, HIGH);
  digitalWrite(MatrixC2, HIGH);

  return rv;
}

bool checkButton(int val, bool* wasLow, unsigned long* lastTime) {
  if (val == LOW && (*wasLow) == true) {
    (*wasLow) = false;
    (*lastTime)=millis();
    return true;
  }
  if (val == HIGH&&(*wasLow)==false) {
    (*lastTime)=millis();
    (*wasLow) = true;
  }
  return false;
}

void loop() {

  button = getButtonPress();

  if (!gameRunning) {
    if (button&START) {
      if (selectedOption == 1) {
        if (!inLeaderboard) {
          inLeaderboard = true;
          button = 0;
          printLeaderBoard();
        } else {
          printWelcomeScreen();
          inLeaderboard = false;
          button = 0;
        }

      } else {
        startGame();
      }
    }


    if (!inLeaderboard && !gameRunning) {

      if (button&UP) {
        selectedOption = 0;
        display.setTextColor(WHITE);

        display.setTextSize(1);
        display.setCursor(34, 55);
        display.println("LEADERBOARD");
      }

      if (button&DOWN) {
        selectedOption = 1;
        display.setTextColor(WHITE);
        display.setTextSize(1);
        display.setCursor(52, 43);
        display.println("START");
      }
      toggleText();
    }


  }


  if (gameRunning) {

    if (button != UP && button != DOWN && button != LEFT && button != RIGHT) {
      button = oldButton;
    }




    control();


    if (borderCross()) {

      gameRunning = false;
      checkHighscore();
      printWelcomeScreen();


      return;

    }



 
if (!collab()) {
 

  for(uint16_t i = 0; i < 4; ++i) {
      display.drawRect(tetro[i].x * SEGMENT_SIZE + 1, tetro[i].y * SEGMENT_SIZE + 1, 2, 2, SSD1306_BLACK);
      tetro[i].y = tetro[i].y + 1;
    } 
    
  for(uint16_t i = 0; i < 4; ++i) {
      display.drawRect(tetro[i].x * SEGMENT_SIZE + 1, tetro[i].y * SEGMENT_SIZE + 1, 2, 2, SSD1306_WHITE);
    }
} else{
      
  for(uint16_t i = 0; i < 4; ++i) {
    tetro[i].y = tetro[i].y - 1;
    field[tetro[i].y] = field[tetro[i].y] | (1 << tetro[i].x);   
  }
  formBlock();
  }
  
  
    button = 0;
    oldButton = 0;

    printTime();
    display.display(); // Daten auf display schreiben.


    delay(SEGMENT_TIME);
  }
}

void checkHighscore() {
  uint16_t time = millis() / 1000 - starttime;


  for (int i = 0; i < 5; i++) {
    char pC16[2];
    pC16[0] = EEPROM.read(i * 3 + 1);
    pC16[1] = EEPROM.read(i * 3 + 2);
    uint16_t readTime;
    memcpy( &readTime, pC16, 2 );
    if (score > EEPROM.read(i * 3) || score == EEPROM.read(i * 3) && readTime > time) {

      for (int j = 4; j > i; j--) {
        EEPROM.write(j * 3, EEPROM.read((j - 1) * 3));
        EEPROM.write(j * 3 + 1, EEPROM.read((j - 1) * 3 + 1));
        EEPROM.write(j * 3 + 2, EEPROM.read((j - 1) * 3 + 2));
      }

      EEPROM.write(i * 3, score);





      EEPROM.write(i * 3 + 1, time & 0xFF);
      EEPROM.write(i * 3 + 2, time >> 8);
      return;
    }
  }
}

void drawBorder() {
  display.drawRect(0, 0, FIELD_SIZE_X * SEGMENT_SIZE + 1, FIELD_SIZE_Y * SEGMENT_SIZE + 1, SSD1306_WHITE);

  display.setTextSize(0.5);

  display.setTextColor(WHITE);
  display.setCursor(98, 0);
  display.println("NEXT");
  display.setCursor(98, 23);
  display.println("SCORE");

//  display.setCursor(98, 45);
 // display.println("Time");
}

void printScore() {
  score = len - 3;
  display.setTextSize(0.5);
  display.setCursor(98, 10);
  if (len > START_LEN) {
    display.setTextColor(BLACK);
    display.println(score - 1);
  }
  display.setCursor(98, 10);
  display.setTextColor(WHITE);
  display.println(len - 3);

  if (score > highscore) {
    highscore = score;
    display.setCursor(98, 33);
    if (highscore != 0) {
      display.setTextColor(BLACK);
      display.println(highscore - 1);
    }
    display.setCursor(98, 33);
    display.setTextColor(WHITE);
    display.println(highscore);
  } else {
    display.setCursor(98, 33);
    display.setTextColor(WHITE);
    display.println(highscore);
  }
}


void printTime() {
  display.setTextSize(0.01);

  display.setTextColor(BLACK);
  display.setCursor(98, 55);


  display.println(oldtime);

  oldtime = millis() / 1000 - starttime;
  display.setTextColor(WHITE);
  display.setCursor(98, 55);


  display.println(oldtime);
}

void formBlock() {
chooseBlocks();
turnstate = 0;
 if(chosenBlock == 0) {
    // I
  tetro[0].x = 3;
  tetro[0].y = 4;
  tetro[1].x = 4;
  tetro[1].y = 4;
  tetro[2].x = 5;
  tetro[2].y = 4;
  tetro[3].x = 6;
  tetro[3].y = 4;

  }else if(chosenBlock == 1) {
    // J
  tetro[0].x = 4;
  tetro[0].y = 3;
  tetro[1].x = 4;
  tetro[1].y = 4;
  tetro[2].x = 5;
  tetro[2].y = 4;
  tetro[3].x = 6;
  tetro[3].y = 4;
  }else if(chosenBlock == 2) {
    // L
  tetro[0].x = 4;
  tetro[0].y = 4;
  tetro[1].x = 4;
  tetro[1].y = 3;
  tetro[2].x = 5;
  tetro[2].y = 3;
  tetro[3].x = 6;
  tetro[3].y = 3;
  }else if(chosenBlock == 3) {
    // O
  tetro[0].x = 4;
  tetro[0].y = 4;
  tetro[1].x = 4;
  tetro[1].y = 3;
  tetro[2].x = 5;
  tetro[2].y = 4;
  tetro[3].x = 5;
  tetro[3].y = 3;
  }else if(chosenBlock == 4) {
    // S
  tetro[0].x = 4;
  tetro[0].y = 4;
  tetro[1].x = 5;
  tetro[1].y = 4;
  tetro[2].x = 5;
  tetro[2].y = 3;
  tetro[3].x = 6;
  tetro[3].y = 3;
  }else if(chosenBlock == 5) {
    // T
  tetro[0].x = 4;
  tetro[0].y = 4;
  tetro[1].x = 5;
  tetro[1].y = 4;
  tetro[2].x = 5;
  tetro[2].y = 3;
  tetro[3].x = 6;
  tetro[3].y = 4;
  }else if(chosenBlock == 6) {
    // Z
  tetro[0].x = 4;
  tetro[0].y = 3;
  tetro[1].x = 5;
  tetro[1].y = 3;
  tetro[2].x = 5;
  tetro[2].y = 4;
  tetro[3].x = 6;
  tetro[3].y = 4; 
  }

      for(uint16_t i = 0; i < 4; ++i) {
      display.drawRect(tetro[i].x * SEGMENT_SIZE + 1, tetro[i].y * SEGMENT_SIZE + 1, 2, 2, SSD1306_WHITE);
    }
 
  display.display(); // daten auf display schreiben.
}



void chooseBlocks() { //generiere einen neuen zufälligen Block

if(firstBlock == true){
chosenBlock = rand() % 7;
firstBlock = false;
}
chosenBlock = nextBlock
nextBlock = rand() % 7;

 display.setCursor(98, 70); // 70 gewählt prüfen !!
 display.println(nextBlock);
 
}



  




void control() {



//if(button==EMPTY){
//  button=oldButton;
//}

  switch (button) {

    case UP:
      if (oldButton == DOWN) {
        button = DOWN;
      }
      break;
    case DOWN:
      if (oldButton == UP) {
        button = UP;
      }
      break;
    case LEFT:
      if (oldButton == RIGHT) {
        button = RIGHT;
      }
      break;
    case RIGHT:
      if (oldButton == LEFT) {
        button = LEFT;
      }
      break;
  }

  oldButton = button;

  switch (button) {
    case UP:

      break;
    case LEFT:
 for(uint16_t i = 0; i < 4; ++i) {
        display.drawRect(tetro[i].x * SEGMENT_SIZE + 1, tetro[i].y * SEGMENT_SIZE + 1, 2, 2, SSD1306_BLACK);
     tetro[i].x = tetro[i].x - 1;
    }
      break;
    case RIGHT:
    for(uint16_t i = 0; i < 4; ++i) {
        display.drawRect(tetro[i].x * SEGMENT_SIZE + 1, tetro[i].y * SEGMENT_SIZE + 1, 2, 2, SSD1306_BLACK);
     tetro[i].x = tetro[i].x + 1;
    }
      break;
    case DOWN:

      break;
  }
  /*
  
  if(button == LEFT) {
 for(uint16_t i = 0; i < 4; ++i) {
        display.drawRect(tetro[i].x * SEGMENT_SIZE + 1, tetro[i].y * SEGMENT_SIZE + 1, 2, 2, SSD1306_BLACK);
     tetro[i].x = tetro[i].x - 1;
    }
} else if(button == RIGHT) {
 for(uint16_t i = 0; i < 4; ++i) {
        display.drawRect(tetro[i].x * SEGMENT_SIZE + 1, tetro[i].y * SEGMENT_SIZE + 1, 2, 2, SSD1306_BLACK);
     tetro[i].x = tetro[i].x + 1;
    }
}

  button = 0;
  oldButton = 0;

 * 
   */
}





bool collab() {
// int a;
// int b;


  for(uint16_t i = 0; i < 4; ++i) {
    if (tetro[i].y > FIELD_SIZE_Y - 2) {
    return true;
   }else if(bitRead(field[tetro[i].y], tetro[i].x) == 1) {
    return true;
   }
  }
  


   
  return false;

}

bool borderCross() {
  if (tetro[0].y > FIELD_SIZE_Y - 1) {
    return true;
  }
  return false;
}

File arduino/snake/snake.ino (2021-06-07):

// License: GPL v2
// Authors: some students from HTBLA Steyr, Austria

/*
 * Features:
 * Lenken mit Steuerkreuz
 * Äpfel fressen
 * Schlange wird pro Apfel um eins länger
 * Geschwindigkeit wird mit jedem Apfel erhöht
 *
 *
 * TODOs:
 * Bugfix, Spiel wird nach 25 Punkten beendet
 * Highscore Liste im ESP-Flash ablegen
 * Punktestand nach Spielende anzeigen
 * Möglichkeit des Pausierens
 */


#include <stdlib.h>
#include <time.h>
#include <SPI.h>
#include <Wire.h>
#include <Adafruit_GFX.h>
#include <Adafruit_SSD1306.h>
#include <ESP_EEPROM.h>
#include <stdint.h>
#include "button.h"


struct Point {
    Point();
    Point(int8_t x, int8_t y);
    bool operator == (Point rhs);
    int8_t x;
    int8_t y;
};
#define SCREEN_WIDTH 128 // OLED display width, in pixels
#define SCREEN_HEIGHT 64 // OLED display height, in pixels


#define SEGMENT_SIZE 3
#define START_LEN 3
#define FIELD_SIZE_X 32
#define FIELD_SIZE_Y 21
#define ARR_LEN 100



// Declaration for an SSD1306 display connected to I2C (SDA, SCL pins)
#define OLED_RESET     -1 // Reset pin # (or -1 if sharing Arduino reset pin)
Adafruit_SSD1306 display(SCREEN_WIDTH, SCREEN_HEIGHT, &Wire, OLED_RESET);


Point snake[ARR_LEN] = {Point(0,0)};

uint16_t headindex;
uint16_t len = START_LEN;
uint8_t score = 0;
uint8_t highscore = 0;
bool gameRunning = false;
bool gamePaused = false;
bool inHighScore = false;
uint8_t selectedOption = 0;
uint16_t oldtime; // seconds
uint16_t starttime; // seconds
Point eatPos;

#define LOGO_HEIGHT   16
#define LOGO_WIDTH    16

enum Direction{UP, DOWN, LEFT, RIGHT};
Direction direction;
#define START_DELAY 500
uint32_t moveDelay=START_DELAY; // start delay in ms


void setup() {
    Serial.begin(115200);
    delay(100);
    Serial.println("Welcome to SNAKE on Gamearino");
    Wire.begin(14,2); // SDA, SCL

    // SSD1306_SWITCHCAPVCC = generate display voltage from 3.3V internally
    if (!display.begin(SSD1306_SWITCHCAPVCC, 0x3C, false, false)) {
        Serial.println(F("SSD1306 allocation failed"));
        for (;;); // Don't proceed, loop forever
    }
    display.clearDisplay();


    // The library needs to know what size you need for your EEPROM variables
    // The minimum size is 16
    // The begin() call is required to initialise the EEPROM library
    EEPROM.begin(16);


    // clear high score TODO with matrix
    if (buttons.start->read() == Button::Pressed &&
            buttons.select->read() == Button::Pressed) {

        for (uint8_t i = 0; i < 15; i++) {
            EEPROM.put(i, 0);
        }
        if(EEPROM.commit()){
            Serial.println("Data written to EEPROM");
        }else{
            Serial.println("Error on EEPROM.commit()");
        }
        buttons.start->clearEvents();
        do{
            buttons.start->read();
        }while(buttons.start->getEvent() != Button::ReleasedEvent);
    }



    // Clear the buffer
    printWelcomeScreen();
}


void startGame() {
    Serial.println("startGame");
    EEPROM.get(0, highscore);

    display.clearDisplay();
    direction = RIGHT;
    drawBorder();
    initializeSnake();
    printScore();
    printTime();
    gameRunning = true;
    starttime = millis() / 1000;
    moveDelay = START_DELAY;
}
void printWelcomeScreen() {
    display.clearDisplay();
    display.setTextSize(1);
    display.setTextColor(WHITE);
    display.setCursor(35, 5);
    display.println("Welcome to:");
    display.setTextSize(2);
    display.setCursor(37, 20);
    display.println("SNAKE");
    display.setTextSize(1);
    display.setCursor(52, 43);
    display.println("START");
    display.setTextSize(1);
    display.setCursor(34, 55);
    display.println("HIGHSCORE");
    display.display();
}

void toggleText() {
    static uint32_t lasttoggle = 0;
    uint32_t now = millis();

    if (now - lasttoggle > 600) {
        lasttoggle = now;
        display.setTextColor(WHITE);
    } else if (now - lasttoggle > 300) {
        display.setTextColor(BLACK);
    } else {
        return;
    }

    if (selectedOption == 0) {
        display.setTextSize(1);
        display.setCursor(52, 43);
        display.println("START");
    } else {
        display.setTextSize(1);
        display.setCursor(34, 55);
        display.println("HIGHSCORE");
    }

    display.display();
}



void loop() {
    buttons.readAll();

    if (!gameRunning) {
        if (buttons.start->getEvent() == Button::PressedEvent) {
            if (selectedOption == 1) {
                if (!inHighScore) {
                    inHighScore = true;
                    paintHighscore();
                } else {
                    printWelcomeScreen();
                    inHighScore = false;
                }
            } else {
                startGame();
            }
        }


        if (!inHighScore && !gameRunning) {

            if (buttons.up->getEvent() == Button::PressedEvent) {
                selectedOption = 0;
                display.setTextColor(WHITE);

                display.setTextSize(1);
                display.setCursor(34, 55);
                display.println("HIGHSCORE");
            }

            if (buttons.down->getEvent() == Button::PressedEvent) {
                selectedOption = 1;
                display.setTextColor(WHITE);
                display.setTextSize(1);
                display.setCursor(52, 43);
                display.println("START");
            }
            toggleText();
        }
    } // end !gameRunning


    if (gameRunning) {
        if(buttons.start->getEvent() == Button::PressedEvent){
            gamePaused = !gamePaused;

            if(!gamePaused){
                repaintField();
            }
        }

        uint32_t now = millis();

        if(!gamePaused){
            control();

            if (bodyCross() || borderCross()) {
                stateDump();

                gameRunning = false;
                updateHighscore();
                printWelcomeScreen();
                return;
            }
        }

        if (snake[headindex] == eatPos) {
            len++;
            newEat();
            moveDelay = 3000/(len+3); // increase speed with length of snake
            printScore();
            display.drawRect(eatPos.x * SEGMENT_SIZE + 1, eatPos.y * SEGMENT_SIZE + 1, 2, 2, SSD1306_WHITE);
        }

        display.drawRect(snake[headindex].x * SEGMENT_SIZE + 1, snake[headindex].y * SEGMENT_SIZE + 1, 2, 2, SSD1306_WHITE);
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

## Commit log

2020-11-09 änderungen aus werkstatt
    [TODO Bauteile für Reset-Programmierschaltung.ods, gamearino.kicad_pcb, gamearino.sch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]
2021-03-15 PCB-Platzierung, 3D-Knöpfe, Schaltung wird noch getestet
    [AB Knopf.step, StartSelect Knopf.step, Steuerkreuz.step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]
2021-03-15 Changelog eingeführt, GND statt GNDD
    [buttons.sch, gamearino.sch, oled.sch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]
2021-03-17 usb.sch Datei war gebrochen, wurde gefixt
    [gamearino.sch, usb.sch]
2021-03-17 Pinliste und kleinere Verschönerungen, Transistor-Value, ...
    [Pinbelegung und Funktionen ESP-12F.ods, autoreset.sch, gamearino.sch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]
2021-04-21 OLED funktioniert, Gehäuse vorläufig fertig
    [ab-button_v2.stl, ab-buttons.FCStd, dummy-pcb.FCStd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]
2021-04-23 Gehäuse updates, Buttons richtig zugewiesen, Tetris
    [buttons.sch, gamearino-gehäuseboden.FCStd, gamearino-gehäuseboden_tag3.FCStd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]
2021-04-26 v0.0.1 für CNC-Fertigung
    [gamearino.kicad_pcb, gamearino.sch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]
2021-04-29 Fertiges Layout v0.0.2, 3 Stk bestellt
    [autoreset.sch, buttons.sch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]
2021-05-04 BOM fertig eingepflegt
    [autoreset.sch, buttons.sch, gamearino.sch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]
2021-05-04 BOM für Bestellung bei LCSC nochmals korrigiert
    [2021-05-04_LCSC_BOM-export.csv, usb.sch]
2021-05-10 Bestellungen LCSC
    [2021-05-04_LCSC_BOM-export.csv, LCSC_Exported_20210504_235939.xlsx, TODO Bauteile für Reset-Programmierschaltung.ods]
2021-05-10 Button class, test buttons
2021-05-10 Soft Watchdog muss immer rückgesetzt werden
    mit delay() loop() oder millis()
2021-05-10 PCB v0.0.2 wieder hergestellt
    [gamearino.kicad_pcb]
2021-05-10 Inbetriebnahme Screenshots und Info
2021-05-10 WIP demo programme Arduino
2021-05-11 Fertige Inbetriebnahme, OLED-Beschaltung korrigiert
    [demo_ssd1306_128x64_i2c.ino, hardware-test.ino, snake.ino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]
2021-05-11 Schaltplanänderungen für v20.0.3 eingepflegt
    [autoreset.sch, buttons.sch, gamearino.sch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]
2021-05-11 Layoutbugfixes, v20.0.3 fertig, CAM-Daten
    [autoreset.sch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]
2021-05-11 76 Stk. bei Multi-CB bestellt
    [gamearino.sch]
2021-05-11 Deckel und Boden optimiert, neu: Loch für Resettaster
    [gamearino-boden_v3.stl, gamearino-deckel_v2.stl, gamearino-gehäuseboden.FCStd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]
2021-05-11 Reset-Taster gestaltet, siehe Github
    https://github.com/KarlZeilhofer/gamearino/issues/13
    [gamearino-button_reset_v1.stl, gamearino-gehäuseboden.FCStd]
2021-05-13 Bisherige Funktion portiert auf Button-Klasse, Bugfix toggleText
    uint32_t für Millisekunden verwenden!
    [button.cpp, snake.ino]
2021-05-14 Snake Bug, Issue#18 behoben
    [snake.ino]
2021-05-14 Highscore: EEPROM für mit der Bibliothek ESP_EEPROM
2021-05-14 Schnell Tasteneingabe verbessert
    Richtungswechsel, die momentan nicht ausgewertet werden, werden auch nicht aus den Events gelöscht, und werden im nächsten Schritt behandelt.
2021-05-14 Bugfix: manchmal gab es bisher unsichtbare Äpfel
    [snake.ino]
2021-05-17 Prusa: Deckel und Boden, Produktionsstart
    [gamearino_deckel-v2_boden-v3.3mf]
2021-05-31 Buttons Prusa
    [gamearino-buttons_20sets.3mf]
2021-06-07 Buttons V3: dünner gestaltet
    [gamearino-button_ab_v3.stl, gamearino-button_ss_v3.stl, gamearino-buttons_8sets_v3.3mf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]
2021-06-09 neueste Button.cpp, verhindert kurzschlüsse von GPIOs
2021-06-09 Button Matrix Bugreport, see Github issue#20
2021-06-21 Prusa: steuerkreuz v2, PLA, 20er Set
    [gamearino-buttons_20sets.3mf, gamearino-steuerkreuz_v2.3mf]
2021-08-10 Update README.md, Hinweise zu Bibliotheken und Spiele
